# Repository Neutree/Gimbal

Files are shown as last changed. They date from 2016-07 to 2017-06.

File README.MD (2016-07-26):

三轴云台
================= 

# 特征
## 自动功能
* 增稳
* 随动模式

## 监控
* 云台检测到有App连接后按0.1Hz的频率向App发送姿态信息（角度、加速度、角速度、磁力计）、收到的遥控数据（角度）、电机输出
* 1Hz的频率输出电压信息

## 控制
* App发送启动/关闭命令，云台做相应动作
* App发送校准命令后，云台进行校准（包括角速度校准、加速度校准、磁力计校准）
* App发出读取PID请求，云台返回PID数据
* App控制云台姿态（角度）

## 硬件组成
* 集中式（一个MCU，三个电机驱动）（包含分布式电路）
* MCU：STM32c8t6
* 驱动芯片：L6234d
* 无刷电机

# 姿态
## 传感器
* 三轴加速度计
* 三轴角速度计
* 三轴磁力计

## 代码风格
看[这里](https://github.com/neutree/simple-code-conventions)

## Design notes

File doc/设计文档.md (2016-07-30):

三轴云台设计文档
==========================

# 硬件设计

# 嵌入式软件设计

## 存储设计
stm32芯片63k处开始储存，格式如下

| 起始标志 |  起始标志 | | | ||||||||||||||||
| --- | --- | --- | --- |-|-|-|-|-|-|-|-|-|-|-|-|-|-|-|-|
|0x00aa| 0x00bb |P_ROLL |I_ROLL| D_ROLL |P_PITCH |I_PITCH |D_PITCH |P_YAW |I_YAW |D_YAW |GYRO_OFFSET_X |GYRO_OFFSE_Y |GYRO_OFFSET_Z |MAG_OFFSET_RATIO_X |MAG_OFFSET_RATIO_Y |MAG_OFFSET_RATIO_Z|MAG_OFFSET_BIAS_X |MAG_OFFSET_BIAS_Y |MAG_OFFSET_BIAS_Z|

PID参数roll、pitch原值存放，yaw乘以1000存放。角速度值按原始值+32768存放。磁力计比例值按值乘以10000存放，偏移量+32768存放。

# 通信设计
详情请见[通信协议文档](./通信协议.md)

# App设计

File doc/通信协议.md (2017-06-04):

三轴云台通信协议
======

## 监控
* 云台检测到有App连接后按0.1Hz的频率向App发送姿态信息（角度、加速度、角速度、磁力计）、收到的遥控数据（角度）、电机输出
* 1Hz的频率输出电压信息

| 名称 | 头 | 标志 | 内容长度 | 内容 | 和校验 | 备注 |
| --- | ---- | ---- | --- | --- | --- | --- |
| 姿态 | AAAA | 01 | LEN | int16 ROL*100</br>int16</br>PIT*100</br>int16 YAW*100</br>int32</br>ALT_USE(高度cm)</br>uint8 MODEL(模式）</br>u8 ARMED : 0加锁 1解锁 | | |
| 传感器 | AAAA | 02 | 18 | int16 ACC_X</br>int16</br>ACC_Y</br>int16 ACC_Z</br>int16 GYRO_X</br>int16 GYRO_Y</br>int16 GYRO_Z</br>int16 MAG_X</br>int16 MAG_Y</br>int16 MAG_Z | | |
| 遥控数据 | AAAA | 03 | 20 | int16 THR</br>int16 YAW</br>int16 ROL</br>int16 PIT</br>int16 AUX1</br>int16 AUX2</br>int16 AUX3</br>int16 AUX4</br>int16 AUX5</br>int16 AUX6 | | |
| 电机 | AAAA | 06 | LEN | uint16 PWM_MOTO12345678 | | 马达输出(范围0-1000) |
| 电压 | AAAA | 05 | LEN | uint16 Votage*100</br>uint16 Current*100 | | |
|调试信息| AAAA | DB | LEN | char*|||

## 控制
* App发送启动/关闭命令，云台做相应动作
* App发送校准命令后，云台进行校准（包括角速度校准、加速度校准、磁力计校准）
* App发出读取PID请求，云台返回PID数据
* App控制云台姿态（角度）

### App->云台

| 名称 | 头 | 标志 | 内容长度 | 内容 | 校验和 | 备注 |
| --- | ---- | ---- | --- | --- | --- | --- |
| 校准、解锁 | AAAF | 01 | 1 | uint8 CMD1 | | 命令集合1</br></br>01：ACC校准</br>02：GYRO校准</br>04：MAG校准</br>05：BARO校准</br>A0：锁定</br>A1：解锁 |
| 请求读取PID | AAAF | 02 | 1 | uint8 CMD2 | | 命令集合2</br>01：读取PID请求（返回AAAA 10\11\12\13\14\15数据帧）</br>02：读取模式设置请求（返回AAAA 0A数据帧） |
| 姿态控制 | AAAF | 03 | 20 |int16 THR</br>int16 YAW</br>int16 ROL</br>int16 PIT</br>int16 AUX1</br>int16 AUX2</br>int16 AUX3</br>int16 AUX4</br>int16 AUX5</br>int16 AUX6 | | |
| 发送PID到云台 | AAAF | 10 | 18 | int16 PID_roll_P</br>int16 PID_roll_I</br>int16 PID_roll_D</br>int16 PID_pitch_P</br>int16 PID_pitch_I</br>int16 PID_pitch_D</br>int16 PID_yaw_P</br>int16 PID_yaw_I</br>int16 PID_yaw_D | | 需要云台返回应答数据 |
| 模式 | AAAF | 0A | LEN | int8 AUX1_LOW_MODEL</br>int8 AUX1_MID_MODEL</br>int8 AUX1_HIG_MODEL</br>int8 AUX2_LOW_MODEL</br>int8 AUX2_MID_MODEL</br>int8 AUX2_HIG_MODEL</br>int8 AUX3_LOW_MODEL</br>int8 AUX3_MID_MODEL</br>int8 AUX3_HIG_MODEL | | |

### 云台->App

| 名称 | 头 | 标志 | 内容长度 | 内容 | 校验和 | 备注 |
| --- | ---- | ---- | --- | --- | --- | --- |
| 模式 | AAAA | 0A | LEN | int8 AUX1_LOW_MODEL</br>int8 AUX1_MID_MODEL</br>int8 AUX1_HIG_MODEL</br>int8 AUX2_LOW_MODEL</br>int8 AUX2_MID_MODEL</br>int8 AUX2_HIG_MODEL</br>int8 AUX3_LOW_MODEL</br>int8 AUX3_MID_MODEL</br>int8 AUX3_HIG_MODEL | | 在接收到App的模式设置后返回 |
| PID数据 | AAAA | 10 | 18 | int16 PID_roll_P</br>int16 PID_roll_I</br>int16 PID_roll_D</br>int16 PID_pitch_P</br>int16 PID_pitch_I</br>int16 PID_pitch_D</br>int16 PID_yaw_P</br>int16 PID_yaw_I</br>int16 PID_yaw_D | | 接收到查询PID命令后返回 |
| 设置PID响应 | AAAA | EF | 2 | uint8  FREAM_HEAD 帧头</br>uint8  CHECK_SUM 和校验 | | 在接收到App的PID设置后返回</br>比如要返回PID1数据帧的校验数据，FREAM_HEAD=0x10，CHECK_SUM=接收到PID1数据帧计算出的SUM |

*通信协议兼容匿名科创地面站V4.06， 可以直接使用*

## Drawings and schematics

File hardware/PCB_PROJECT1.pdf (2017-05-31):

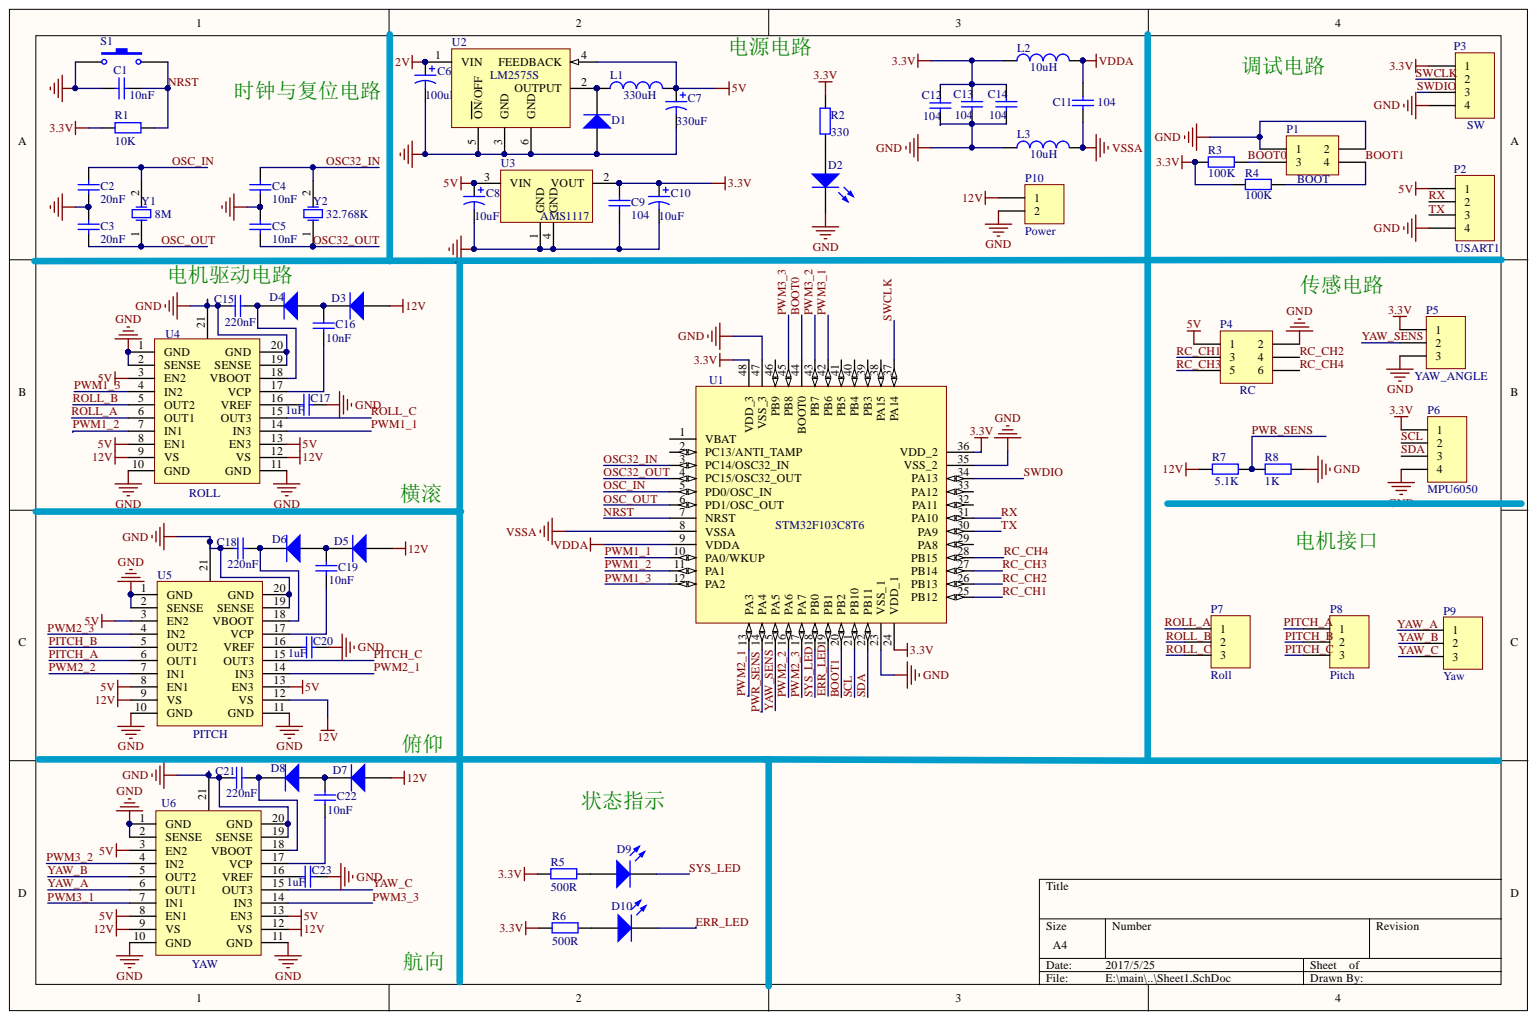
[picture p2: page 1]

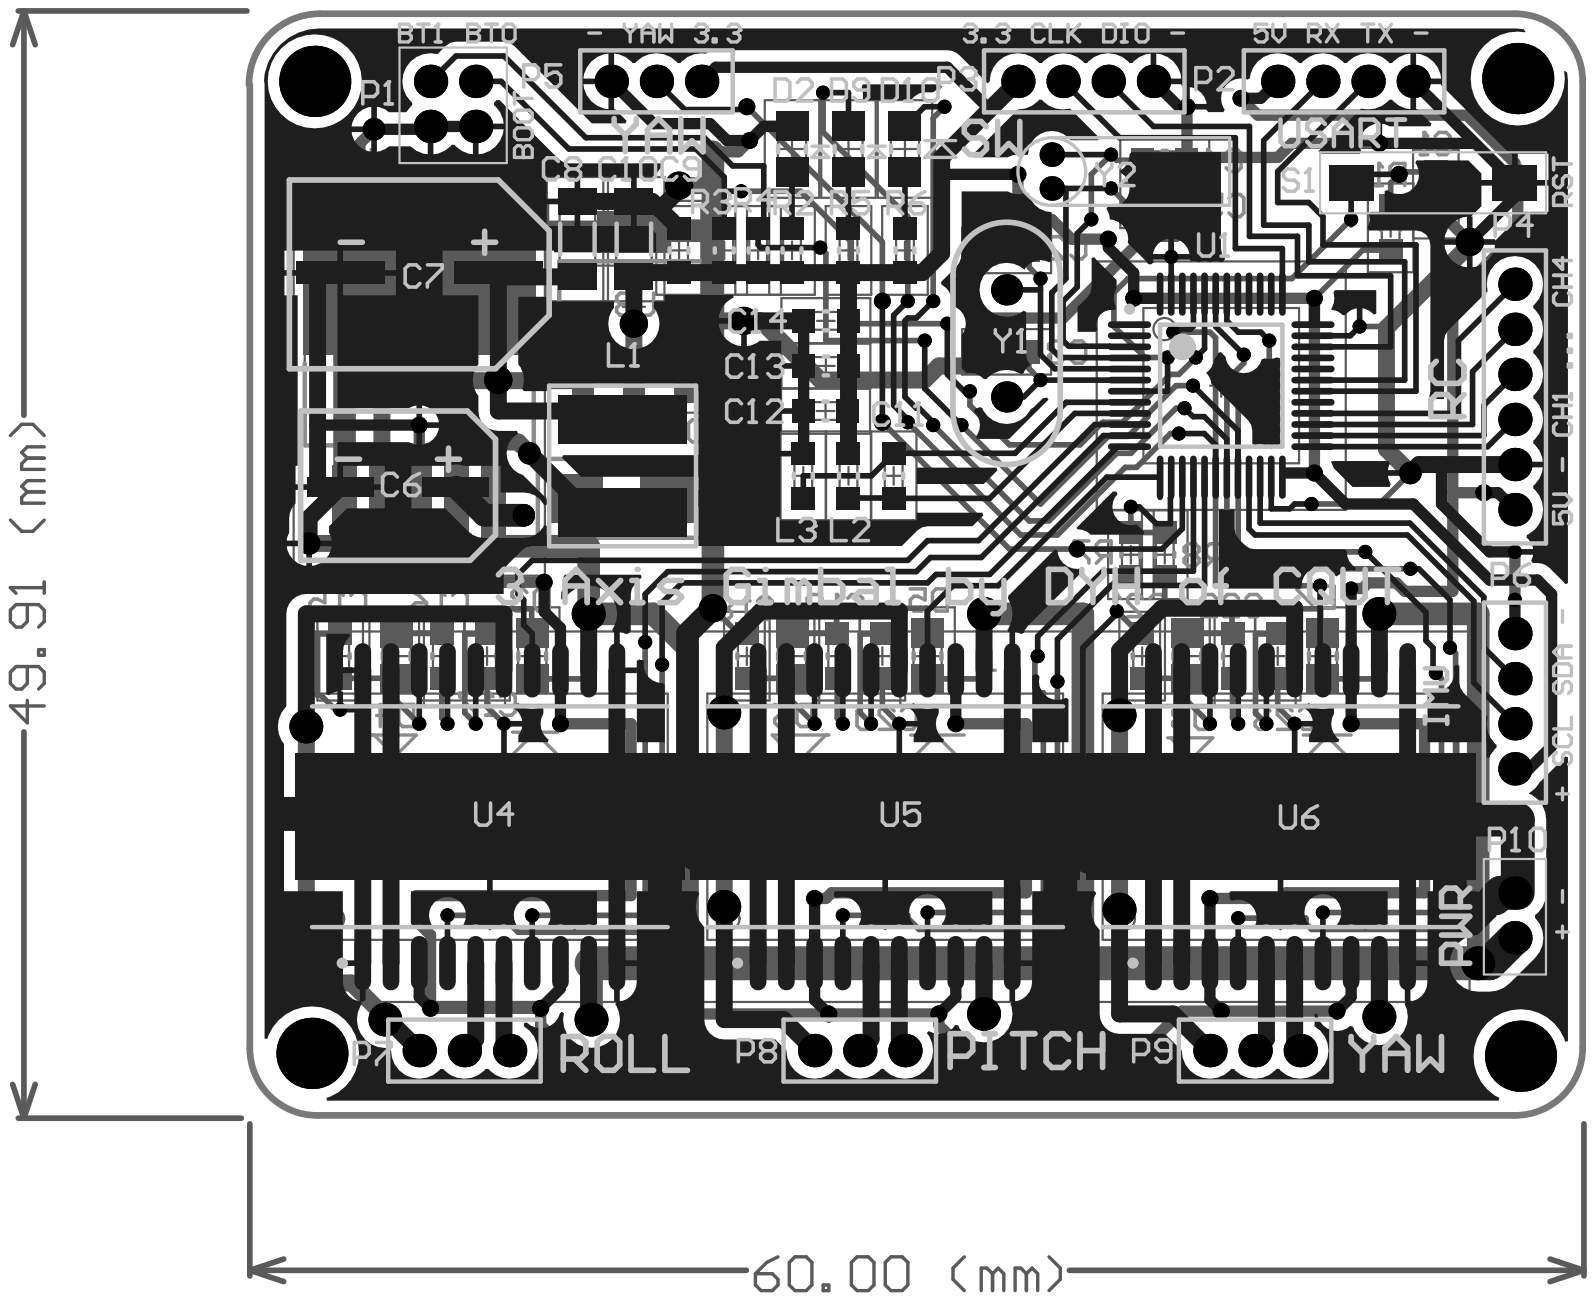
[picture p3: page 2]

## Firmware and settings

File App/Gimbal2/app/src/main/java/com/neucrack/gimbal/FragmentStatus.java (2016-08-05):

package com.neucrack.gimbal;

import android.content.Context;
import android.net.Uri;
import android.os.Bundle;
import android.os.Handler;
import android.os.Message;
import android.support.v4.app.Fragment;
import android.util.Log;
import android.view.LayoutInflater;
import android.view.View;
import android.view.ViewGroup;
import android.widget.TextView;


public class FragmentStatus extends Fragment {
    private static final String ARG_PARAM1 = "param1";
    private static final String ARG_PARAM2 = "param2";

    private String mParam1;
    private String mParam2;
    private TextView mAngleRoll,mAnglePitch,mAngleYaw, mAccX,mAccY,mAccZ, mGyroX,mGyroY,mGyroZ, mMagX,mMagY,mMagZ, mMotorRoll,mMotorPitch,mMotorYaw, mVoltage;


    @Override
    public void onCreate(Bundle savedInstanceState) {
        super.onCreate(savedInstanceState);
        if (getArguments() != null) {
            mParam1 = getArguments().getString(ARG_PARAM1);
            mParam2 = getArguments().getString(ARG_PARAM2);
        }


    }


    @Override
    public View onCreateView(LayoutInflater inflater, ViewGroup container,
                             Bundle savedInstanceState) {
        View view = inflater.inflate(R.layout.fragment_fragment_status, container, false);
        mAngleRoll = (TextView) view.findViewById(R.id.textView_angle_roll);
        mAnglePitch = (TextView) view.findViewById(R.id.textView_angle_pitch);
        mAngleYaw =  (TextView) view.findViewById(R.id.textView_angle_yaw);
        mAccX = (TextView) view.findViewById(R.id.textView_acc_x);
        mAccY = (TextView) view.findViewById(R.id.textView_acc_y);
        mAccZ = (TextView) view.findViewById(R.id.textView_acc_z);
        mGyroX = (TextView) view.findViewById(R.id.textView_gyro_x);
        mGyroY = (TextView) view.findViewById(R.id.textView_gyro_y);
        mGyroZ = (TextView) view.findViewById(R.id.textView_gyro_z);
        mMagX = (TextView) view.findViewById(R.id.textView_mag_x);
        mMagY = (TextView) view.findViewById(R.id.textView_mag_y);
        mMagZ = (TextView) view.findViewById(R.id.textView_mag_z);
        mMotorRoll = (TextView) view.findViewById(R.id.textView_motor_roll);
        mMotorPitch = (TextView) view.findViewById(R.id.textView_motor_pitch);
        mMotorYaw = (TextView) view.findViewById(R.id.textView_motor_yaw);
        mVoltage = (TextView) view.findViewById(R.id.textView_voltage);

        return view;
    }

    public void showAngle(double roll,double pitch,double yaw){
        Bundle data = new Bundle();
        data.putDouble("roll",roll);
        data.putDouble("pitch",pitch);
        data.putDouble("yaw",yaw);
        Message msg = new Message();
        msg.setData(data);
        setAngle.sendMessage(msg);
    }

    Handler setAngle = new Handler(){
        @Override
        public void handleMessage(Message msg) {
            super.handleMessage(msg);
            Bundle data = msg.getData();
            double roll = data.getDouble("roll",0);
            double pitch = data.getDouble("pitch",0);
            double yaw = data.getDouble("yaw",0);
            mAngleRoll.setText(roll+"°");
            mAnglePitch.setText(pitch+"°");
            mAngleYaw.setText(yaw+"°");
        }
    };

    public void showRawData(double acc_x, double acc_y, double acc_z, int gryo_x, int gryo_y, int gryo_z, int mag_x, int mag_y, int mag_z) {

        Bundle data = new Bundle();
        data.putDouble("acc_x",acc_x);
        data.putDouble("acc_y",acc_y);
        data.putDouble("acc_z",acc_z);
        data.putInt("gyro_x",gryo_x);
        data.putInt("gyro_y",gryo_y);
        data.putInt("gyro_z",gryo_z);
        data.putInt("mag_x",mag_x);
        data.putInt("mag_y",mag_y);
        data.putInt("mag_z",mag_z);
        Message msg = new Message();
        msg.setData(data);
        setRawData.sendMessage(msg);
    }
    Handler setRawData = new Handler(){
        @Override
        public void handleMessage(Message msg) {
            super.handleMessage(msg);
            Bundle data = msg.getData();
            double acc_z = data.getDouble("acc_z",0);
            double acc_x = data.getDouble("acc_x",0);
            double acc_y = data.getDouble("acc_y",0);
            int gyro_x = data.getInt("gyro_x",0);
            int gyro_y = data.getInt("gyro_y",0);
            int gyro_z = data.getInt("gyro_z",0);
            int mag_x = data.getInt("mag_x",0);
            int mag_y = data.getInt("mag_y",0);
            int mag_z = data.getInt("mag_z",0);
            mAccX.setText(acc_x+"");
            mAccY.setText(acc_y+"");
            mAccZ.setText(acc_z+"");
            mGyroX.setText(gyro_x+"");
            mGyroY.setText(gyro_y+"");
            mGyroZ.setText(gyro_z+"");
            mMagX.setText(mag_x+"");
            mMagY.setText(mag_y+"");
            mMagZ.setText(mag_z+"");
        }
    };



    public void showRCData(double rc_roll, double rc_pitch, double rc_yaw) {
    }

    public void showVoltage(double voltage) {
        Bundle data = new Bundle();
        data.putDouble("voltage",voltage);
        Message msg = new Message();
        msg.setData(data);
        setVoltage.sendMessage(msg);
    }
    Handler setVoltage = new Handler(){
        @Override
        public void handleMessage(Message msg) {
            super.handleMessage(msg);
            Bundle data = msg.getData();
            double voltage = data.getDouble("voltage",0);
            mVoltage.setText(voltage+"V");
        }
    };
    public void showMotor(int motor_roll, int motor_pitch, int motor_yaw) {
        Bundle data = new Bundle();
        data.putInt("roll",motor_roll);
        data.putInt("pitch",motor_pitch);
        data.putInt("yaw",motor_yaw);
        Message msg = new Message();
        msg.setData(data);
        setMotor .sendMessage(msg);
    }

    Handler setMotor = new Handler(){
        @Override
        public void handleMessage(Message msg) {
            super.handleMessage(msg);
            Bundle data = msg.getData();
            int roll = data.getInt("roll",0);
            int pitch = data.getInt("pitch",0);
            int yaw = data.getInt("yaw",0);
            mMotorRoll.setText(roll+"");
            mMotorPitch.setText(pitch+"");
            mMotorYaw.setText(yaw+"");
        }
    };
}

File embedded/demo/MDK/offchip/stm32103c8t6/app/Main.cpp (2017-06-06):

#include "stm32f10x.h"
#include "Configuration.h"
#include "TaskManager.h"
#include "USART.h"
#include "I2C.h"
#include "Timer.h"
#include "ADC.h"
#include "PWM.h"
#include "flash.h"
#include "InputCapture_TIM.h"
#include "InputCapture_EXIT.h"
#include "LED.h"
#include "mpu6050.h"
#include "HMC5883L.h"
#include "BLDCMotor.h"
#include "Flash.h"


#include "Communicate.h"
#include "Gimbal.h"
/************************************硬件定义*************************************/
//Timer T1(TIM1,1,2,3); //使用定时器计，溢出时间:1S+2毫秒+3微秒
USART com(1,115200,false);
I2C i2c2(2); 
mpu6050 mpu6050(i2c2,1000);
HMC5883L mag(i2c2,1000);
PWM pwm2(TIM2,1,1,1,1,20000);  //开启时钟2的4个通道，频率2Whz
PWM pwm3(TIM3,1,1,0,0,20000);  //开启时钟3的2个通道，频率2Whz
PWM pwm4(TIM4,1,1,1,0,20000);  //开启时钟4的3个通道，频率2Whz
//InputCapture_TIM t4(TIM4, 400, true, true, true, true);
//InputCapture_EXIT ch1(GPIOB,6);
ADC adcArray(4,5); //读取ADC value
flash infoStore(0x08000000+63*MEMORY_PAGE_SIZE,true);     //flash


//LED
GPIO ledGreenGPIO(GPIOB,0,GPIO_Mode_Out_PP,GPIO_Speed_50MHz);//LED GPIO
GPIO ledBlueGPIO(GPIOB,1,GPIO_Mode_Out_PP,GPIO_Speed_50MHz);//LED GPIO
LED ledGreen(ledGreenGPIO);//LED red
LED ledBlue(ledBlueGPIO);//LED blue

//BLDC Motor
BLDCMotor motorRoll(&pwm2,1,&pwm2,2,&pwm2,3,0.6);  //roll motor
BLDCMotor motorPitch(&pwm2,4,&pwm3,1,&pwm3,2,0.4); //pitch motor
BLDCMotor motorYaw(&pwm4,1,&pwm4,2,&pwm4,3,0.55);   //yaw motor


/**************************************************************************/


/*************************全局变量*****************************************/

Gimbal gimbal(mpu6050,mag,motorRoll,motorPitch,motorYaw,adcArray,4,5,infoStore);

Communicate communicate(gimbal,com);

/**************************************************************************/



/**
  *系统初始化
  *
  */
void init()
{
	ledBlue.Off();
	ledGreen.Off();
	if(mpu6050.Init())
		ledBlue.On();
	if(mag.Init())
		ledGreen.On();
	gimbal.Init(1);//电位器控制yaw轴，参数为2表示磁力计作为yaw轴的数据
	gimbal.mIsArmed = true;
	gimbal.mYawMode = 1;//跟随模式
}

int motorValueRoll,motorValuePitch,motorValueYaw;

/**
  *循环体
  *
  */
void loop()
{
	 static double updateSlice=0, dataSendSlice= 0,voltageSendTimeSlice=0; //taskmanager时间 测试
	
	//系统运行指示灯，1s闪烁一次
	ledBlue.Blink(0,0.5,false);
	//更新姿态、控制电机，500Hz
 	if(tskmgr.TimeSlice(updateSlice,0.002)) //每0.002秒(500Hz)执行一次
 	{
 		gimbal.UpdateIMU();//更新姿态
 		gimbal.UpdateMotor(&motorValueRoll,&motorValuePitch,&motorValueYaw);//控制电机
 	}
	
 	//输出电源值和飞机姿态数据、电机数据。12.5Hz
 	if(tskmgr.TimeSlice(dataSendSlice,0.1)) 
 	{
 //		if(gimbal.IsGyroCalibrated() && gimbal.IsMagCalibrated())//已经校准完毕
 //		{
 			ledGreen.Toggle();
 			communicate.ANO_DT_Send_Status(gimbal.mAngle.y*RtA,gimbal.mAngle.x*RtA,gimbal.mAngle.z*RtA,0,1,gimbal.mIsArmed);
 			//communicate.ANO_DT_Send_MotoPWM(motorValueRoll%256+256,motorValuePitch%256+256,motorValueYaw%256+256,0,0,0,0,0);
 			communicate.ANO_DT_Send_MotoPWM(motorValueRoll,motorValuePitch,motorValueYaw,0,0,0,0,0);
 			//communicate.ANO_DT_Send_Power(gimbal.UpdateVoltage(4,5.1,1,12)*100,0);
 			if(!gimbal.IsMagCalibrated())
 				communicate.ANO_DT_Send_Senser(mpu6050.GetAcc().x*1000,mpu6050.GetAcc().y*1000,mpu6050.GetAcc().z*1000,mpu6050.GetGyrRaw().x,mpu6050.GetGyrRaw().y,mpu6050.GetGyrRaw().z,mag.xMaxMinusMin,mag.yMaxMinusMin,mag.zMaxMinusMin,0);
 			else
 				communicate.ANO_DT_Send_Senser(mpu6050.GetAcc().x*1000,mpu6050.GetAcc().y*1000,mpu6050.GetAcc().z*1000,mpu6050.GetGyrRaw().x,mpu6050.GetGyrRaw().y,mpu6050.GetGyrRaw().z,mag.GetDataRaw().x,mag.GetDataRaw().y,mag.GetDataRaw().z,0);
 			communicate.ANO_DT_Send_RCData(0,(gimbal.mTargetAngle.z+180)*2.77778+1000,(gimbal.mTargetAngle.y+180)*2.77778+1000,(gimbal.mTargetAngle.x+180)*2.77778+1000,0,0,0,0,0,0);
 //		}
 //		else if(gimbal.IsGyroCalibrating()||gimbal.IsMagCalibrating())
 //			LOG("..");
//			com<<mpu6050.GetAcc().x<<"\t"<<mpu6050.GetAcc().y<<"\t"<<mpu6050.GetAcc().z<<"\t"<<mpu6050.GetGyrRaw().x<<"\t"<<mpu6050.GetGyrRaw().y<<"\t"<<mpu6050.GetGyrRaw().z<<"\t"<<mag.GetDataRaw().x<<"\t"<<mag.GetDataRaw().y<<"\t"<<mag.GetDataRaw().z<<"\n";
		
 	}
	
 	if(tskmgr.TimeSlice(voltageSendTimeSlice,2)) 
 	{
 		if(gimbal.IsGyroCalibrated() && gimbal.IsMagCalibrated())//已经校准完毕
 		{
 			communicate.ANO_DT_Send_Power(gimbal.UpdateVoltage(5.1,1,12)*100,0);
 		}
 	}
	
 	//处理来自地面站的消息
 	communicate.ANO_DT_Data_Receive_Deal(gimbal);
}


int main()
{
	TaskManager::DelayS(3);//延时，等待传感器上电自启动完毕
	init();	
	while(1)
	{
		loop();
	}
}

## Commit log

2016-07-20 init commit
    [Configuration.h]
2016-07-20 6 axis attitude algrithm ok
    [Configuration.h]
2016-07-21 add magnetometer to AHRS fusion
2016-07-22 AHRS fusion and PID control basicly complete
2016-07-25 PID setting
2016-07-26 add magnetometer offset
2016-07-26 debug magnetometer initialize error
    [Main.cpp]
2016-07-26 deleter unuseful files and change directory name
    [Configuration.h]
2016-07-28 complete gyro and magnetometer calibrate
2016-07-28 fix magnetometer store bug
    [Main.cpp]
2016-07-30 control .....lot to do
    [Configuration.h]
2016-08-04 debug: fix bug that remain detect connection after activity Destroyed
    [FragmentStatus.java]
2016-08-04 沉浸式状态栏
2016-08-05 fix bug for staus display
    [FragmentStatus.java]
2016-10-19 fix datagram socket error
2016-10-19 fix received data deal error
    [Main.cpp]
2017-05-11 add hardware PCB
    [PCB1.PcbDoc, PCB3.PcbDoc, PCB_PROJECT1.PRJPCB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]
2017-05-23 fix usart bug & change flash store
    [Gimbal.cpp]
2017-06-05 remove PCB logo
    [PCB3.PcbDoc]
